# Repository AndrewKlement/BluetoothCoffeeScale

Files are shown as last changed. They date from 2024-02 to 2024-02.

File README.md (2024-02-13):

# BluetoothCoffeeScale
A bluetooth coffee scale that can connect to a [recipe app](https://github.com/AndrewKlement/Recipe) and track coffee brewing. 

The printable files can be found at 
https://www.printables.com/model/763335-diy-bluetooth-coffee-scale

# PCB
<a href="https://github.com/AndrewKlement/BluetoothCoffeeScale/assets/104044603/926dc91b-4a7d-49a8-b9fd-27c66a3c3d6e" target="_blank">
        image missing </a>

<a href="https://github.com/AndrewKlement/BluetoothCoffeeScale/assets/104044603/13dd6ade-1279-498f-b7d4-27611ea70281" target="_blank">
        image missing </a>

<a href="https://github.com/AndrewKlement/BluetoothCoffeeScale/assets/104044603/76e948a8-e026-444a-9f98-44f5b6cc3408" target="_blank">
        image missing </a>

# Images
<a href="https://github.com/AndrewKlement/BluetoothCoffeeScale/assets/104044603/61a8941a-3d53-4931-b057-033ae30e1f99" target="_blank">
        image missing </a>

<a href="https://github.com/AndrewKlement/BluetoothCoffeeScale/assets/104044603/539ea249-a03c-4785-a80e-a41a9cfdc55d" target="_blank">
        image missing </a>

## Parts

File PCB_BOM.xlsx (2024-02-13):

Part Occurrences | Count | Price/piece | Price
MOMENTARY-SWITCH-SPST-SMD-4.6X2.8MM | 2 | Rp 2000.00 | Rp 4000.00
0.1uF C_CHIP-0402(1005-METRIC) | 2 | Rp 100.00 | Rp 200.00
10uF C_CHIP-0805(2012-METRIC) | 3 | Rp 599.00 | Rp 1797.00
1uF C_CHIP-0603(1608-METRIC) | 1 | Rp 199.00 | Rp 199.00
4.7uF C_CHIP-0603(1608-METRIC) | 1 | Rp 399.00 | Rp 399.00
4.7uF C_CHIP-0402(1005-METRIC) | 1 | Rp 249.00 | Rp 249.00
0.1uF C_CHIP-0603(1608-METRIC) | 6 | Rp 149.00 | Rp 894.00
10uF C_CHIP-1210(3225-METRIC) | 2 | Rp 2999.00 | Rp 5998.00
SS12-TP SS12-TP | 1 | Rp 600.00 | Rp 600.00
LED_YELLOW CHIP-FLAT-Y_0603-0.80MM | 1 | Rp 125.00 | Rp 125.00
CHIP-FLAT-B_0603-0.80MM | 128 | Rp 100.00 | Rp 12800.00
BM06B-SRSS-TB(LF)(SN) BM06B-SRSS-TB(LF)(SN) | 1 | Rp 3000.00 | Rp 3000.00
BM04B-SRSS-TB(LF)(SN) BM04B-SRSS-TB(LF)(SN) | 1 | Rp 2500.00 | Rp 2500.00
3A/250V B2B-XH-A | 1 | Rp 2500.00 | Rp 2500.00
3.3uH L_CHIP-0805(2012-METRIC) | 1 | Rp 1200.00 | Rp 1200.00
600mA/40V TRANS_PNP-MMBT4403 | 1 | Rp 1399.00 | Rp 1399.00
MMBT3904 MMBT3904 | 2 | Rp 100.00 | Rp 200.00
5.1k R_CHIP-0603(1608-METRIC) | 2 | Rp 250.00 | Rp 500.00
100k R_CHIP-0603(1608-METRIC) | 2 | Rp 100.00 | Rp 200.00
1k R_CHIP-0402(1005-METRIC) | 1 | Rp 100.00 | Rp 100.00
2k R_CHIP-0603(1608-METRIC) | 1 | Rp 100.00 | Rp 100.00
10k R_CHIP-0402(1005-METRIC) | 3 | Rp 100.00 | Rp 300.00
20k R_CHIP-0603(1608-METRIC) | 1 | Rp 100.00 | Rp 100.00
8.2k R_CHIP-0603(1608-METRIC) | 1 | Rp 100.00 | Rp 100.00
10k R_CHIP-0603(1608-METRIC) | 3 | Rp 100.00 | Rp 300.00
0.1k R_CHIP-0603(1608-METRIC) | 2 | Rp 100.00 | Rp 200.00
MAX17048 MAX17048DFN8 | 1 | Rp 13138.00 | Rp 13138.00
TM1640 TM1640 | 1 | Rp 12000.00 | Rp 12000.00
ESP32-WROOM-32E_(4MB_HIGH_TEMP) ESP32-WROOM-32E_(4MB_HIGH_TEMP) | 1 | Rp 50000.00 | Rp 50000.00
DMG3415U-7 DMG3415U-7 | 1 | Rp 2019.60 | Rp 2019.60
CH340C CH340C | 1 | Rp 16000.00 | Rp 16000.00
AP2112K-3.3TRG1 AP2112K-3.3TRG1 | 1 | Rp 6200.00 | Rp 6200.00
MCP73831 MCP73831 | 1 | Rp 9800.00 | Rp 9800.00
HX711 HX711 | 1 | Rp 8310.00 | Rp 8310.00
TOTAL |  |  | Rp 157427.60

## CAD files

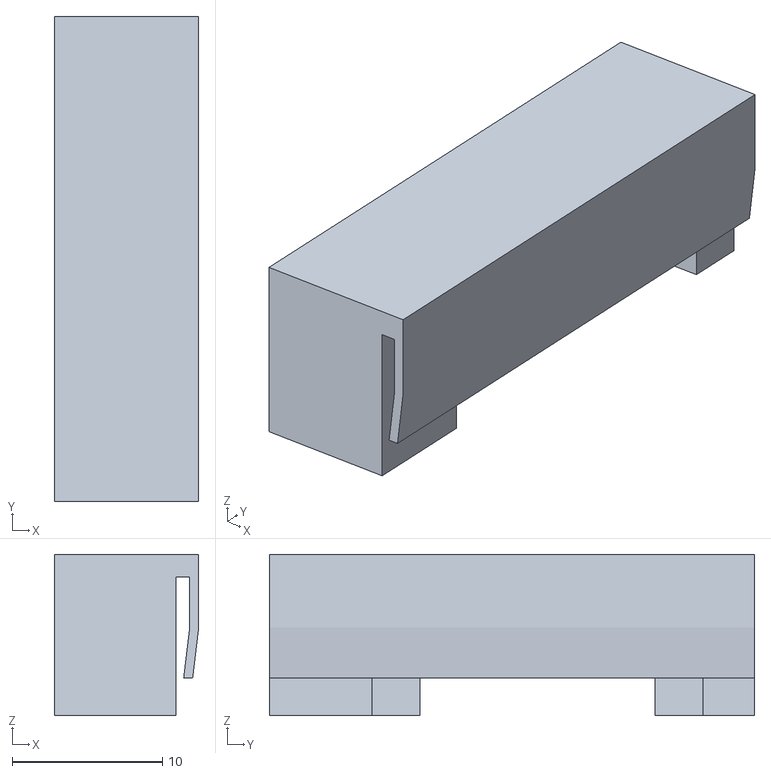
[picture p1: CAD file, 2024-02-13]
Bluetooth Scale V3 STL/USBC Clip.stl
9.60 x 32.2 x 10.7

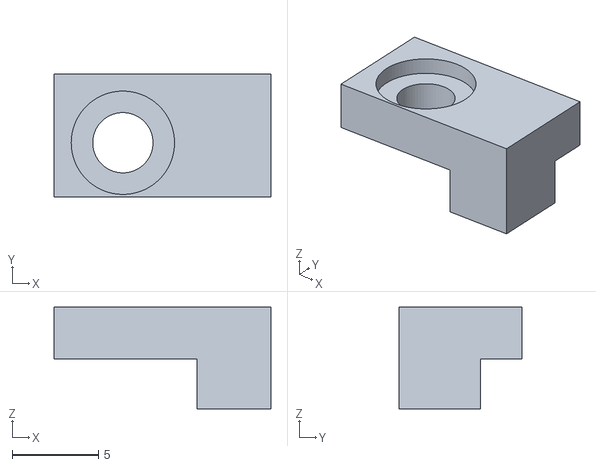
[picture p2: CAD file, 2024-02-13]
Bluetooth Scale V3 STL/PCB Holder L.stl
12.6 x 7.16 x 5.89

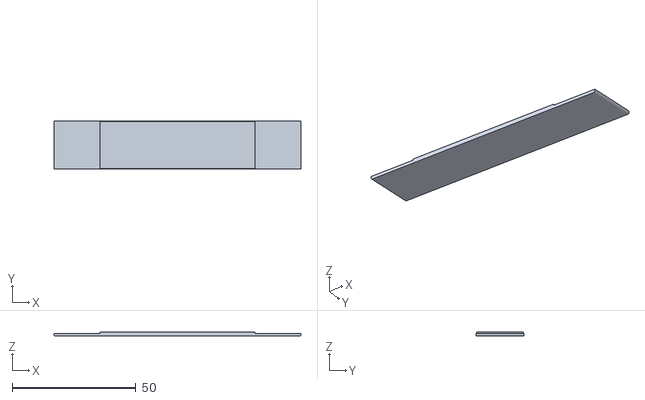
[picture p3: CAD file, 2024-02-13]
Bluetooth Scale V3 STL/LED Window.stl
100.0 x 19.5 x 1.80

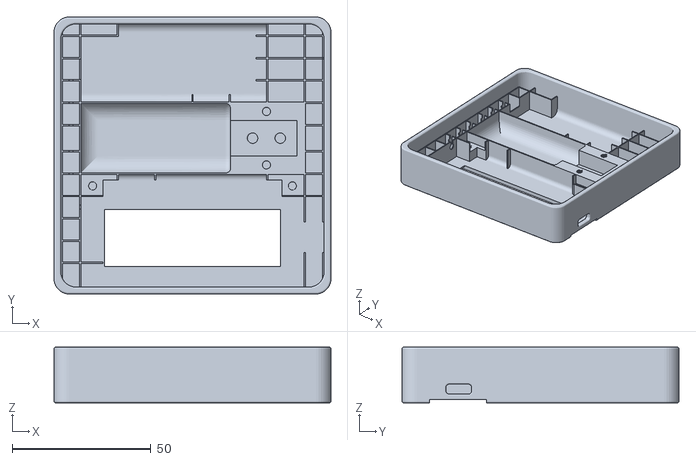
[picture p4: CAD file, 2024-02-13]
Bluetooth Scale V3 STL/Top Cover.stl
100.0 x 100.0 x 20.2

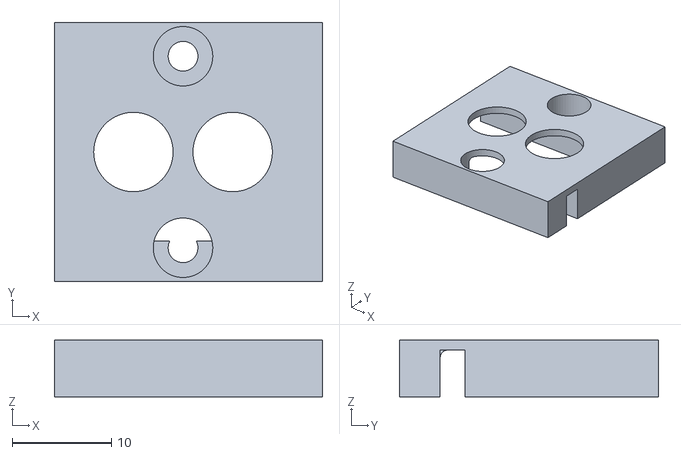
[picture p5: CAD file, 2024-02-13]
Bluetooth Scale V3 STL/Top Cover Load Cell Holder.stl
27.0 x 26.1 x 5.70

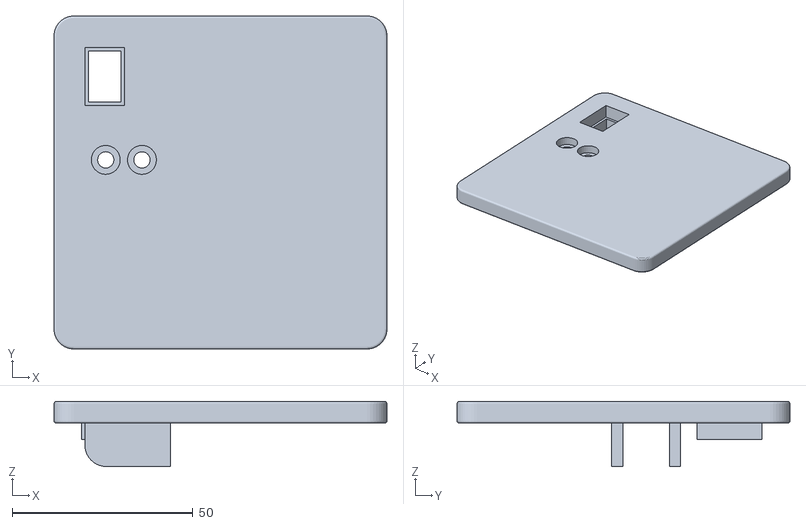
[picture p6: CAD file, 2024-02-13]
Bluetooth Scale V3 STL/Bottom Cover.stl
92.0 x 92.0 x 18.0

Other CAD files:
Bluetooth Scale V3 STL/PCB Holder R.stl

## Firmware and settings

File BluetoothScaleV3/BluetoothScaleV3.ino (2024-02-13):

#include <Arduino.h>
#include "HX711.h"
#include "soc/rtc.h"
#include <Wire.h>
#include <Adafruit_GFX.h>
#include <Adafruit_SSD1306.h>
#include <TM1640.h>           //LED matrix chip libary
#include <TM16xxMatrixGFX.h>  
#include <Fonts/Picopixel.h>
#include <string>
#include "BluetoothSerial.h"
#include <Preferences.h>

#if !defined(CONFIG_BT_ENABLED) || !defined(CONFIG_BLUEDROID_ENABLED)
#error Bluetooth is not enabled! Please run `make menuconfig` to and enable it
#endif

#if !defined(CONFIG_BT_SPP_ENABLED)
#error Bluetooth not available or not enabled.
#endif

// HX711
const int LOADCELL_DOUT_PIN = 16;
const int LOADCELL_SCK_PIN = 4;
HX711 scale;

//LED Matrix
TM1640 module(21, 22);    // I2C connection for LED matrix
#define MODULE_SIZECOLUMNS 16    // number of GRD lines, will be the y-height of the display
#define MODULE_SIZEROWS 8    // number of SEG lines, will be the x-width of the display
TM16xxMatrixGFX matrix(&module, MODULE_SIZECOLUMNS, MODULE_SIZEROWS);    // TM16xx object, columns, rows

//BluetoothSerial
BluetoothSerial SerialBT;

//flash memory
Preferences preferences;

//variable
float last_batteryLevel = 0.0;
bool start_rec = false; 
float lastReading = 0.0;
float avarageScale = 0;
int counter = 0;
float reading = 0;
bool display_text = false; 

void displayText(String text){
  matrix.fillScreen(LOW); 
  matrix.write();
  matrix.setCursor(0,7);
  matrix.print(text);
  matrix.write();
}

void setup() {
  Serial.begin(115200);
  
  // Scale Begin
  scale.begin(LOADCELL_DOUT_PIN, LOADCELL_SCK_PIN);
  
  scale.set_scale(230.9026);
  scale.tare(); 
  //LED Matrix 8x16
  matrix.setIntensity(5); // Use a value between 0 and 7 for brightness
  matrix.setRotation(1);
  matrix.setMirror(true); 
  matrix.setFont(&Picopixel);
  
  //Bluetooth Begin
  SerialBT.begin("Scale");

  // Scale begin at 0 g
  displayText("CON");
  SerialBT.print(String(0)); 
}

void loop() {
  if (SerialBT.available()) {
    String bt_reading = SerialBT.readString();
    if (bt_reading == "tare") {
      scale.tare(); 
    } 
    if (bt_reading == "calibrate") {
      scale.set_scale();
      displayText("CLR");
      delay(4000);
      scale.tare();
      delay(4000); 
      displayText(String(500));
      delay(4000); 
      int reading = scale.get_units(40);
      int calibration_factor = reading/500; 
      scale.set_scale(calibration_factor);
      preferences.begin("factor", false);
      preferences.putFloat("cal_factor", calibration_factor);
      preferences.end();
      delay(4000); 
    }        
  }  
  float foo = scale.get_units(15); 
  int reading = round(foo); 
  Serial.println(reading);
  if (lastReading != reading){
    if (reading >= 0){
        lastReading = reading;
        displayText(String(reading));
        Serial.println(String(reading));
        SerialBT.print(String(reading)); 
    }
    else{
      displayText(String(0));
      Serial.println(String(reading));
      SerialBT.print(String(0)); 
    } 
  }
}
